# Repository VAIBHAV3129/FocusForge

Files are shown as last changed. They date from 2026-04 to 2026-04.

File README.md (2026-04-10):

FocusForge

# FocusForge
FocusForge is designed to be a ESP32 powered which basically helps you focus( as in the name itself) it helps users to maintain a state of flow and creates a dedicated environment for deep work.

# Key Features
- It has an integrated VL53L0X ToF Sensor automatically pauses the session if you leave your desk.
- High-quality KY-040 Rotary Encoder to toggle between different focus intensities.
- OLED Display for session progress and an that changes color based on focus depth
- Battery-powered via a LiPo cell with integrated TP4056 charging.
Safe Logic: TXS0108E Level Shifter ensures stable communication between 3.3V and 5V components.

# Technical Details
- Microcontroller: ESP32 
- Communication: I2C Bus for display and distance sensing.
- Firmware: Written in C++/Arduino.
- Hardware: Parametric enclosure designed in Onshape.

# Bill of Materials

| Name | Purpose | Quantity | | Link | Distributor |
|---|---|---|---|---|---|
| TXS0108E | to protect my esp32 from the 5v logic and provide stable 3.3v | 1 | | https://robu.in/product/txs0108e-high-speed-full-duplex-8-channel-logic-level-converter/ | robu.in |
| USB to MicroUSB cable | to develop the esp32 | 1 | | https://robu.in/product/usb-to-micro-usb-cable-wire-1m-for-nodemcu/ | robu.in |
| TP4056 | for charging the battery | 1 | | https://robu.in/product/tp4056-1a-li-ion-lithium-battery-charging-module-with-current-protection-type-c/ | robu.in |
| KY-040 Rotary Encoder Module | Dial for selecting focus modes | 1 | | https://quartzcomponents.com/products/rotary-encoder-module-ky-040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 | Quartz Components |
| 1.3" I2C OLED | for displaying info | 1 | | https://robu.in/product/128x64-i2c-communication-interface-oled-display/ | robu.in |
| LiPo Battery (3.7V) | to power the device | 1 | | https://quartzcomponents.com/products/3-7v-10000mah-li-po-rechargeable-battery?_pos=1&_sid=b1bf49bca&_ss=r | Quartz Components |
| ToF Sensor (VL53L0X) | Presence Detection | 1 | | https://robu.in/product/vl53l0x-tof-based-lidar-laser-distance-sensor/ | robu.in |
| ESP32 Expansion Board 38PIN  | To expand the pins in esp32 | 1 | | https://robu.in/product/esp32-development-board-type-c-micro-usb-esp32-expansion-board-38pin-female-header/ | Robu.in |
| ESP32 Development Board | Main microcontroller (controls inputs, display, LEDs) | 1 | | https://quartzcomponents.com/products/esp32-development-board-wifi-bluetooth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 | Quartz Components |
| Other minor components | Breadboard, Jumperwires etc for prototyping | as necessary | | 

## Wiring 

1774971280608-ixl5uo

# Power & Ground 

- 3.3V Rail: Connect the ESP32 3V3 pin to the VCC/VIN pins of the OLED display, the VL53L0X sensor, and the Rotary Encoder.

- Ground Rail: Connect any GND pin on the ESP32 to the GND/COM pins of the OLED, VL53L0X, RGB LED, Buzzer, Rotary Encoder, and the standalone Pushbutton.

# I2C Communication (Shared Bus)

- Data (SDA): Connect ESP32 GPIO 21 to the SDA pin on the OLED and the SDA pin on the VL53L0X sensor.

- Clock (SCL): Connect ESP32 GPIO 22 to the SCL pin on the OLED and the SCL pin on the VL53L0X sensor.

# User Inputs 

- Rotary Clock: Connect ESP32 GPIO 18 to the CLK pin of the encoder.

- Rotary Data: Connect ESP32 GPIO 19 to the DT pin of the encoder.

- Encoder Switch: Connect ESP32 GPIO 4 to the SW pin of the encoder.

- Main Button: Connect ESP32 GPIO 32 to one side of your Pushbutton.

# Feedback System 

- Red Channel: Connect ESP32 GPIO 25 to the Red pin of the RGB LED.

- Green Channel: Connect ESP32 GPIO 26 to the Green pin of the RGB LED.

- Blue Channel: Connect ESP32 GPIO 27 to the Blue pin of the RGB LED.

- Buzzer Alert: Connect ESP32 GPIO 13 to the positive terminal (Pin 2) of the Buzzer.

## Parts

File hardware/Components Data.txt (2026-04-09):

# Main Control & Power

ESP32 Development Board (38-pin DevKit V1): * Size: ~52mm x 28mm (approx. 25.4mm width for the narrow version).

Height: ~12mm (including pins).

ESP32 Expansion Board (38-pin): * Size: 78mm x 63mm.

Mounting Holes: Usually at the four corners; check the PCB for exact spacing before placing pillars in Onshape.

LiPo Battery (3.7V 1000mAh): * Size: ~35mm x 38mm x 6.6mm.

Note: Batteries can vary slightly by manufacturer; leave at least 2mm of extra space for expansion.

# User Interface (Lid Cutouts)

1.3" I2C OLED Display (SH1106): * PCB Size: 35.4mm x 33.5mm.

Viewing Area (Cutout): 29.4mm x 14.7mm.

KY-040 Rotary Encoder: * PCB Base: 30mm x 18mm.

Shaft Diameter: 7mm ( 7.5mm hole for clearance).

Shaft Height: 20mm ( lid height accounts for this).

# Sensors & Power Regulation

ToF Sensor (VL53L0X Breakout): * Size: 13mm x 18mm x 2mm.

Lens Placement: The sensor itself is a tiny black square in the center; your cutout should align with this.

TP4056 Charging Module: * Size: 25mm x 19mm.

Port: The Micro-USB port sticks out slightly (~1-2mm); your side-wall cutout needs to account for this depth.

TXS0108E Logic Level Shifter: * Size: ~26mm x 15mm.

MCP1700-3302E Regulator: * Package: TO-92 (Through-hole).

Size: 4.7mm x 4.6mm. It’s small, like a transistor.

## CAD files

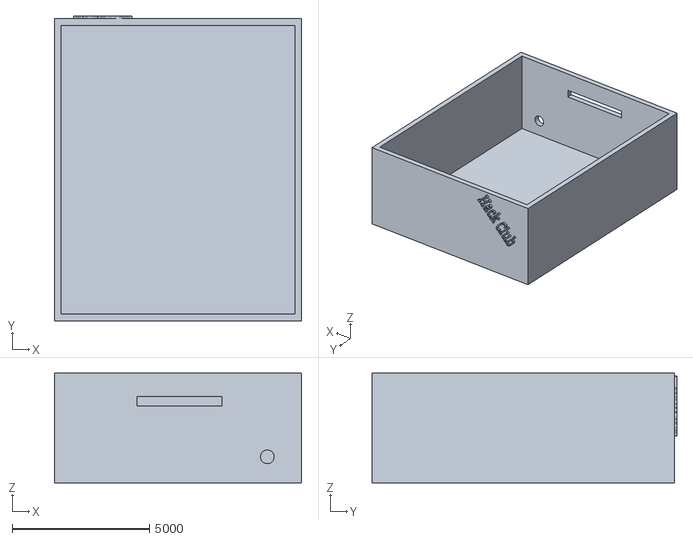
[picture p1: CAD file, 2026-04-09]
Enclosure FF Base.stl
9000.0 x 11100.0 x 4000.0

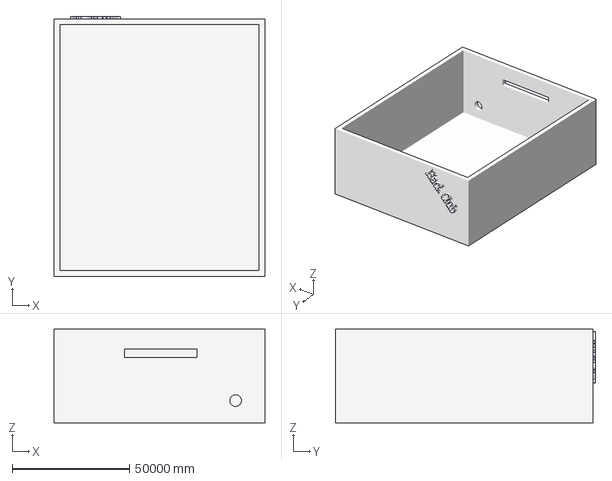
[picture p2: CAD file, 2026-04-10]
hardware/FocusForge Enclosure Base.step
90000.0 x 111000.0 x 40000.0 mm

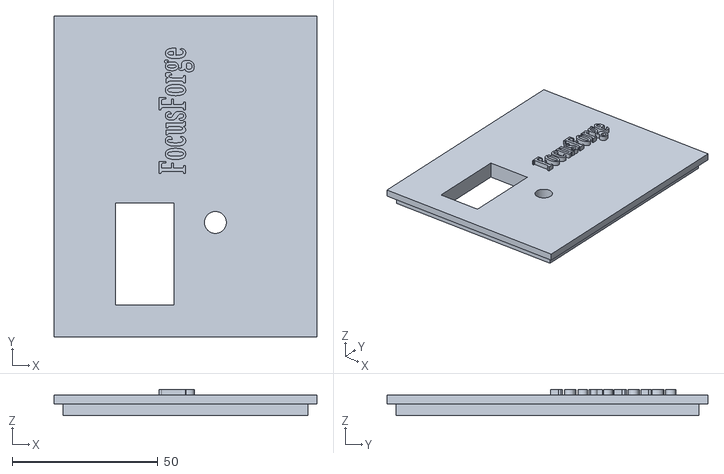
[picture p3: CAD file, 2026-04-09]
Enclosure Lid FF.stl
90.0 x 110.0 x 9.00

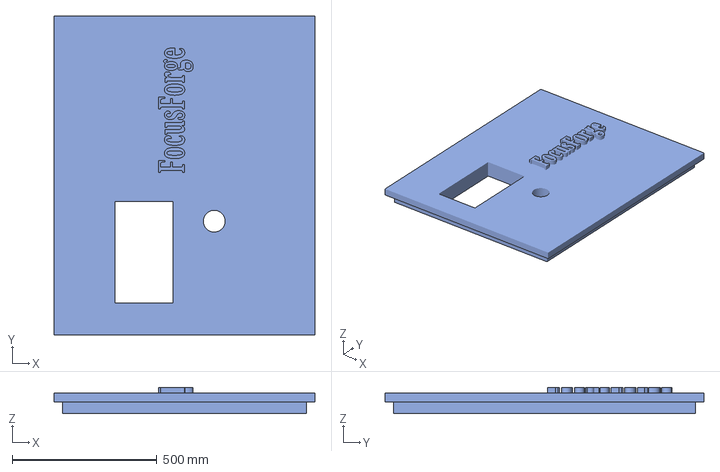
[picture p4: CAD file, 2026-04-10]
hardware/FocusForge Enclosure lid.step
900.0 x 1100.0 x 90.0 mm

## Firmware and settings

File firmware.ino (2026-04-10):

#include <Wire.h>
#include <Adafruit_GFX.h>
#include <Adafruit_SSD1306.h>
#include <Adafruit_VL53L0X.h>
#include <ESP32Encoder.h>

#define ENC_CLK 18
#define ENC_DT  19
#define ENC_SW  4
#define RGB_R   25
#define RGB_G   26
#define RGB_B   27
#define BUZZER  13
#define BUTTON  32
#define SDA_PIN 21
#define SCL_PIN 22

Adafruit_SSD1306 display(128, 64, &Wire, -1);
Adafruit_VL53L0X lox = Adafruit_VL53L0X();
ESP32Encoder encoder;

enum State { IDLE, WORKING, BREAK, ALARM };
State deviceState = IDLE;

struct FocusMode {
  String name;
  int workMin;
  int breakMin;
  int r, g, b;
};

FocusMode modes[] = {
  {"LIGHT", 25, 5, 0, 255, 150},
  {"DEEP", 50, 10, 0, 100, 255},
  {"HYPER", 90, 15, 255, 0, 255}
};

int currentModeIdx = 0;
long timeLeftSeconds = 0;
long totalSessionSeconds = 0;
unsigned long lastTick = 0;
bool presenceDetected = true;

void updateRGB(int r, int g, int b) {
  analogWrite(RGB_R, r);
  analogWrite(RGB_G, g);
  analogWrite(RGB_B, b);
}

void playSound(String type) {
  if (type == "START") {
    tone(BUZZER, 1500, 100);
    delay(150);
    tone(BUZZER, 2000, 200);
  } else if (type == "SUCCESS") {
    tone(BUZZER, 1000, 100);
    delay(100);
    tone(BUZZER, 1500, 100);
    delay(100);
    tone(BUZZER, 2000, 300);
  } else if (type == "WARN") {
    tone(BUZZER, 800, 100);
    delay(100);
    tone(BUZZER, 800, 100);
  }
}

void startSession() {
  playSound("START");
  deviceState = WORKING;
  totalSessionSeconds = modes[currentModeIdx].workMin * 60;
  timeLeftSeconds = totalSessionSeconds;
  lastTick = millis();
}

void triggerAlarm() {
  playSound("SUCCESS");
  deviceState = (deviceState == WORKING) ? BREAK : IDLE;
  if (deviceState == BREAK) {
    totalSessionSeconds = modes[currentModeIdx].breakMin * 60;
    timeLeftSeconds = totalSessionSeconds;
  }
}

void resetToIdle() {
  deviceState = IDLE;
  noTone(BUZZER);
  updateRGB(0, 0, 0);
}

void checkPresence() {
  VL53L0X_RangingMeasurementData_t measure;
  lox.rangingTest(&measure, false);
  presenceDetected = (measure.RangeMilliMeter < 1000 && measure.RangeStatus != 4);
  
  if (!presenceDetected && deviceState == WORKING) {
    analogWrite(RGB_R, 255);
    analogWrite(RGB_G, 0);
    analogWrite(RGB_B, 0);
    if (millis() % 2000 < 100) playSound("WARN");
  } else {
    updateRGB(modes[currentModeIdx].r, modes[currentModeIdx].g, modes[currentModeIdx].b);
  }
}

void handleInputs() {
  if (deviceState == IDLE) {
    long newCount = encoder.getCount() / 2;
    if (newCount != currentModeIdx) {
      currentModeIdx = constrain(newCount, 0, 2);
      encoder.setCount(currentModeIdx * 2);
    }
  }

  if (digitalRead(BUTTON) == LOW || digitalRead(ENC_SW) == LOW) {
    delay(200);
    if (deviceState == IDLE) startSession();
    else if (deviceState == BREAK || deviceState == WORKING) resetToIdle();
  }
}

void updateLogic() {
  if (deviceState == WORKING || deviceState == BREAK) {
    if (millis() - lastTick >= 1000) {
      lastTick = millis();
      if (timeLeftSeconds > 0) {
        timeLeftSeconds--;
        if (deviceState == WORKING) checkPresence();
      } else {
        triggerAlarm();
      }
    }
  }
}

void updateUI() {
  display.clearDisplay();
  display.setTextColor(WHITE);
  
  if (deviceState == IDLE) {
    display.setTextSize(1);
    display.setCursor(35, 0); display.print("SELECT MODE");
    display.setTextSize(2);
    display.setCursor(25, 25); display.print(modes[currentModeIdx].name);
    display.setTextSize(1);
    display.setCursor(25, 50); display.printf("%d min work", modes[currentModeIdx].workMin);
  } else {
    display.setTextSize(1);
    display.setCursor(0, 0); 
    display.print(deviceState == WORKING ? "FOCUSING..." : "BREAK TIME");
    int m = timeLeftSeconds / 60;
    int s = timeLeftSeconds % 60;
    display.setTextSize(3);
    display.setCursor(20, 20);
    display.printf("%02d:%02d", m, s);
    int barWidth = map(timeLeftSeconds, 0, totalSessionSeconds, 0, 128);
    display.drawRect(0, 55, 128, 7, WHITE);
    display.fillRect(0, 55, 128 - barWidth, 7, WHITE);
  }
  display.display();
}

void setup() {
  pinMode(RGB_R, OUTPUT);
  pinMode(RGB_G, OUTPUT);
  pinMode(RGB_B, OUTPUT);
  pinMode(BUZZER, OUTPUT);
  pinMode(BUTTON, INPUT_PULLUP);
  pinMode(ENC_SW, INPUT_PULLUP);
  
  Wire.begin(SDA_PIN, SCL_PIN);
  display.begin(SSD1306_SWITCHCAPVCC, 0x3C);
  lox.begin();
  
  encoder.attachHalfQuad(ENC_CLK, ENC_DT);
  encoder.setCount(0);
  
  display.clearDisplay();
  display.setTextSize(1);
  display.setCursor(30, 25);
  display.print("FOCUS FORGE");
  display.display();
  delay(1000);
}

void loop() {
  handleInputs();
  updateLogic();
  updateUI();
}

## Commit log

2026-03-31 Update .gitignore to include Arduino and Mac OS files
    Added entries for Arduino, ESP32, and Mac OS system files.
2026-04-09 Document hardware specifications and layout
    Added detailed specifications for hardware components including ESP32 board, battery, display, encoder, sensors, and power regulation.
2026-04-10 Rename FocusForge Enclosure Base.step to hardware/FocusForge Enclosure Base.step
    [FocusForge Enclosure Base.step]
2026-04-10 Rename FocusForge Enclosure lid.step to hardware/FocusForge Enclosure lid.step
    [FocusForge Enclosure lid.step]
2026-04-10 Update README with wiring and user input details
    Added wiring and user input sections to README.
